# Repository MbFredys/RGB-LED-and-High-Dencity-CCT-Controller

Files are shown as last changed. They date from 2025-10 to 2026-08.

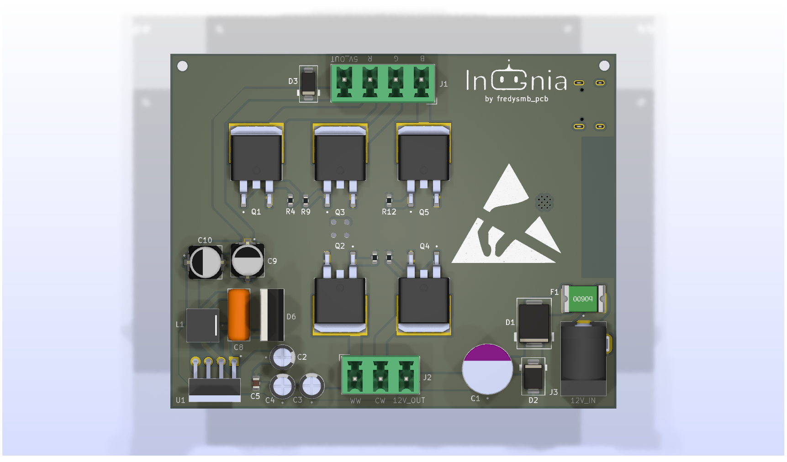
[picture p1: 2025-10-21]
Release/bottom.png

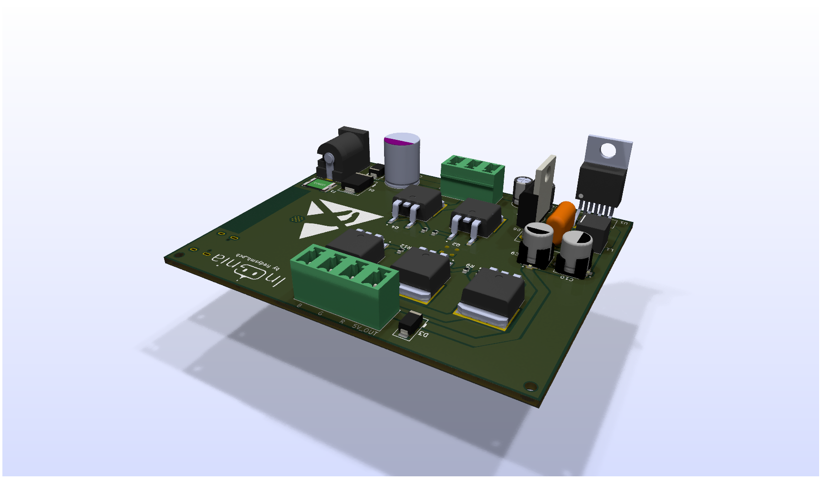
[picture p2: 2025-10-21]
Release/3D-3.png

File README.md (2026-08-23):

# RGB + CCT LED Controller



Five-channel RGB and tunable-white LED-controller PCB based on the ESP32-C3.

> **Project status:** Design and manufacturing documentation completed. The PCB has not been fabricated, thermally characterized, or electrically validated under load.

## Project objective

The project explores a compact controller capable of driving RGB, warm-white, and cool-white LED channels while integrating wireless control, local power conversion, and USB-C programming.

## Hardware architecture

- **Controller:** ESP32-C3-WROOM-02
- **Outputs:** Five low-side PWM channels: R, G, B, warm white, and cool white
- **Switching devices:** IRLZ44N MOSFETs
- **Power input:** 12 V nominal
- **Conversion:** LM2678T-ADJ buck stage and TPS7A20 3.3 V regulation
- **Programming:** USB-C interface
- **Protection:** Input fuse and transient-protection components
- **Connections:** Dedicated RGB and CCT output connectors

## Engineering work

- Defined the functional and power architecture
- Selected the controller, switching devices, regulators, and protection components
- Developed the schematic and PCB layout in KiCad
- Separated high-current and logic routing
- Prepared the BOM and manufacturing documentation

## Key design considerations

- MOSFET conduction losses and gate drive at 3.3 V
- Copper width, connector rating, and total current distribution
- Regulator thermal performance
- PWM return-current paths
- Bulk capacitance near LED outputs
- ESP32 antenna clearance and noise coupling

## Validation still required

Physical testing is required to establish:

- Safe continuous current per channel
- MOSFET and regulator temperatures
- Voltage-drop and connector performance
- PWM behavior with representative LED strips
- Wireless performance during switching
- Protection response and EMC/EMI behavior

The intended current ratings are design targets and must not be treated as validated operating limits.

## License

Licensed under CERN-OHL-W-2.0.

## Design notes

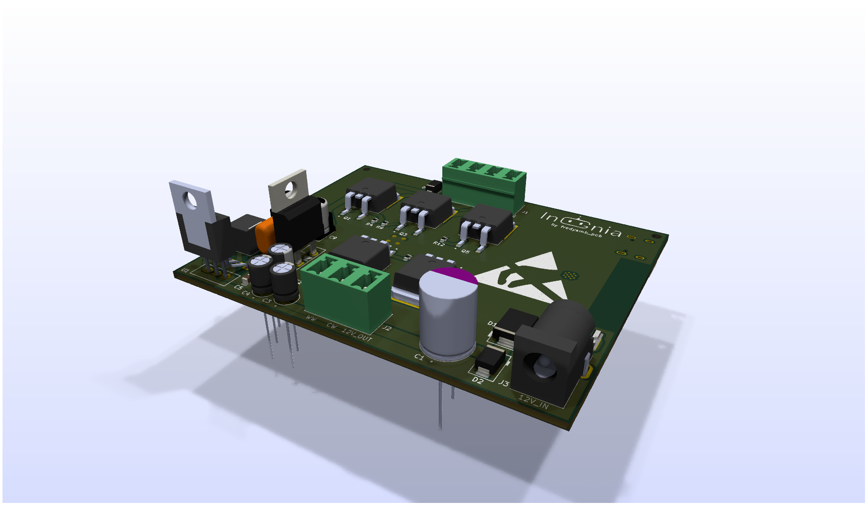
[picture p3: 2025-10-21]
Release/3D-1.png

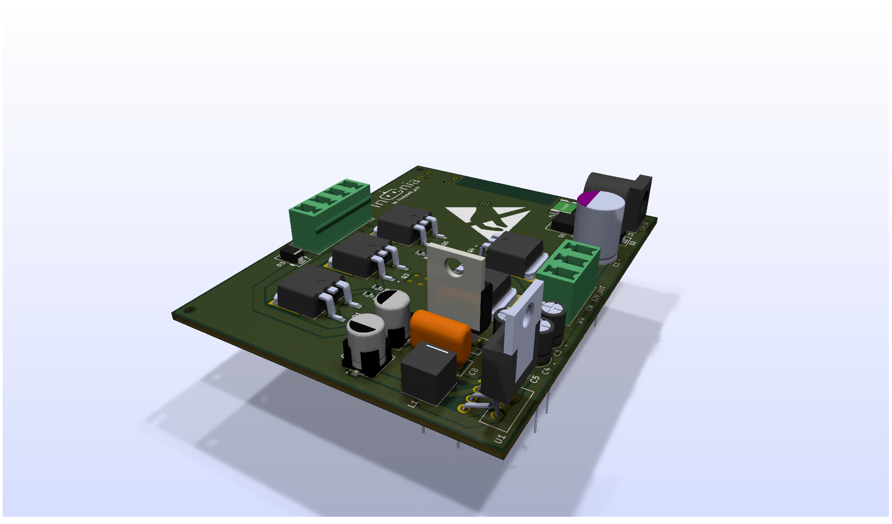
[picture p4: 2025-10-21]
Release/3D-4.png

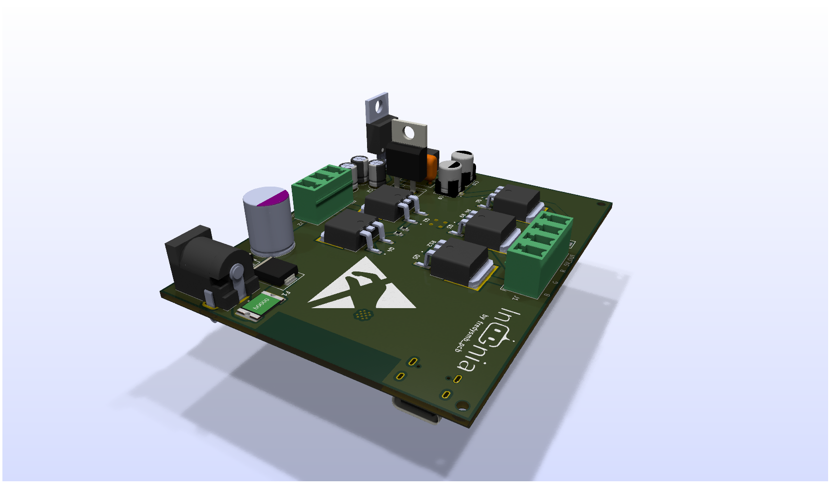
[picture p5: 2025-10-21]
Release/3D-2.png

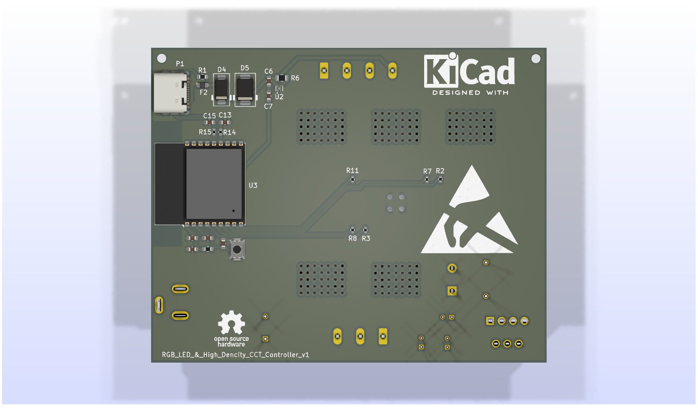
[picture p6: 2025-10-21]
Release/top.png

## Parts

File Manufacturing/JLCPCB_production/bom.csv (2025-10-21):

Designator | Footprint | Quantity | Value | LCSC Part #
C1 | CAPPRD500W60D1000H1300 | 1 | 1000uF
C10, C9 | CAP_EEEFNE181XUV | 2 | 180uF
C11 | 0603 | 1 | 10uF
C12, C14 | 0603 | 2 | 0.1uF
C13, C15 | 0603 | 2 | 22pF
C16, C6, C7 | 0603 | 3 | 1uF
C2, C3, C4 | CAPPRD200W45D500H700 | 3 | 15uF
C5 | 0805 | 1 | 0.47uF
C8 | CAPRR750W60L1030T440H750 | 1 | 0.01uF
D1 | D_SMC | 1 | SS54
D2, D5 | D_SMB | 2 | SMBJ12A
D3 | D_SMA | 1 | SMAJ5.0A
D4 | D_SMA | 1 | SS14
D6 | TO-220-2_Vertical_KA | 1 | MBR735
F1 | FUSC7351X170N | 1 | Polyfuse
F2 | FUSC1608X100N | 1 | Polyfuse
J1 | PhoenixContact_MCV_1,5_4-G-5.08_1x04_P5.08mm_Vertical | 1 | RGB_Strip
J2 | PhoenixContact_MCV_1,5_3-G-5.08_1x03_P5.08mm_Vertical | 1 | CW/WW_Strip
J3 | MPD_EJ503A | 1 | CON_12VDC_IN
L1 | IND_XAL6060-223MEB | 1 | 22uH
P1 | USB_C_Receptacle_GCT_USB4105-xx-A_16P_TopMnt_Horizontal | 1 | USB_C_Plug_USB2.0
Q1, Q2, Q3, Q4, Q5 | TO254P1524X483-4N | 5 | IRLZ44N
R1 | 0603 | 1 | 5.1k
R10, R12, R13, R4, R9 | 0603 | 5 | 10k
R11, R2, R3, R7, R8 | 0402 | 5 | 100
R14, R15 | 0402 | 2 | 22
R5 | 0603 | 1 | 100k
R6 | 0805 | 1 | 100k
SW1 | SW_Push_SPST_NO_Alps_SKRK | 1 | uC_Reset
U1 | TO127P1041X469X2199-7N | 1 | LM2678T-ADJ
U2 | Texas_X2SON-4_1x1mm_P0.65mm | 1 | TPS7A20xxxDQN
U3 | ESP32-C3-WROOM-02 | 1 | ESP32-C3-WROOM-02

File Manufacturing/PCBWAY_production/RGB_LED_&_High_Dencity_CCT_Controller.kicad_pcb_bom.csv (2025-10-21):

Designator | Quantity | Value | Footprint | Package | MPN | DNP | Mount_Type
C1 | 1 | 1000uF | CAPPRD500W60D1000H1300 |  |  |  | tht
C10, C9 | 2 | 180uF | CAP_EEEFNE181XUV |  |  |  | smt
C11 | 1 | 10uF | C_0603_1608Metric |  |  |  | smt
C12, C14 | 2 | 0.1uF | C_0603_1608Metric |  |  |  | smt
C13, C15 | 2 | 22pF | C_0603_1608Metric |  |  |  | smt
C16, C6, C7 | 3 | 1uF | C_0603_1608Metric |  |  |  | smt
C2, C3, C4 | 3 | 15uF | CAPPRD200W45D500H700 |  |  |  | tht
C5 | 1 | 0.47uF | C_0805_2012Metric |  |  |  | smt
C8 | 1 | 0.01uF | CAPRR750W60L1030T440H750 |  |  |  | tht
D1 | 1 | SS54 | D_SMC |  |  |  | smt
D2, D5 | 2 | SMBJ12A | D_SMB |  |  |  | smt
D3 | 1 | SMAJ5.0A | D_SMA |  |  |  | smt
D4 | 1 | SS14 | D_SMA |  |  |  | smt
D6 | 1 | MBR735 | TO-220-2_Vertical_KA |  |  |  | tht
F1 | 1 | Polyfuse | FUSC7351X170N |  |  |  | smt
F2 | 1 | Polyfuse | FUSC1608X100N |  |  |  | smt
J1 | 1 | RGB_Strip | PhoenixContact_MCV_1,5_4-G-5.08_1x04_P5.08mm_Vertical |  |  |  | tht
J2 | 1 | CW/WW_Strip | PhoenixContact_MCV_1,5_3-G-5.08_1x03_P5.08mm_Vertical |  |  |  | tht
J3 | 1 | CON_12VDC_IN | MPD_EJ503A |  |  |  | tht
L1 | 1 | 22uH | IND_XAL6060-223MEB |  |  |  | smt
P1 | 1 | USB_C_Plug_USB2.0 | USB_C_Receptacle_GCT_USB4105-xx-A_16P_TopMnt_Horizontal |  |  |  | smt
Q1, Q2, Q3, Q4, Q5 | 5 | IRLZ44N | TO254P1524X483-4N |  |  |  | smt
R1 | 1 | 5.1k | R_0603_1608Metric |  |  |  | smt
R10, R12, R13, R4, R9 | 5 | 10k | R_0603_1608Metric |  |  |  | smt
R11, R2, R3, R7, R8 | 5 | 100 | R_0402_1005Metric |  |  |  | smt
R14, R15 | 2 | 22 | R_0402_1005Metric |  |  |  | smt
R5 | 1 | 100k | R_0603_1608Metric |  |  |  | smt
R6 | 1 | 100k | R_0805_2012Metric |  |  |  | smt
SW1 | 1 | uC_Reset | SW_Push_SPST_NO_Alps_SKRK |  |  |  | smt
U1 | 1 | LM2678T-ADJ | TO127P1041X469X2199-7N |  |  |  | tht
U2 | 1 | TPS7A20xxxDQN | Texas_X2SON-4_1x1mm_P0.65mm |  |  |  | smt
U3 | 1 | ESP32-C3-WROOM-02 | ESP32-C3-WROOM-02 |  |  |  | smt

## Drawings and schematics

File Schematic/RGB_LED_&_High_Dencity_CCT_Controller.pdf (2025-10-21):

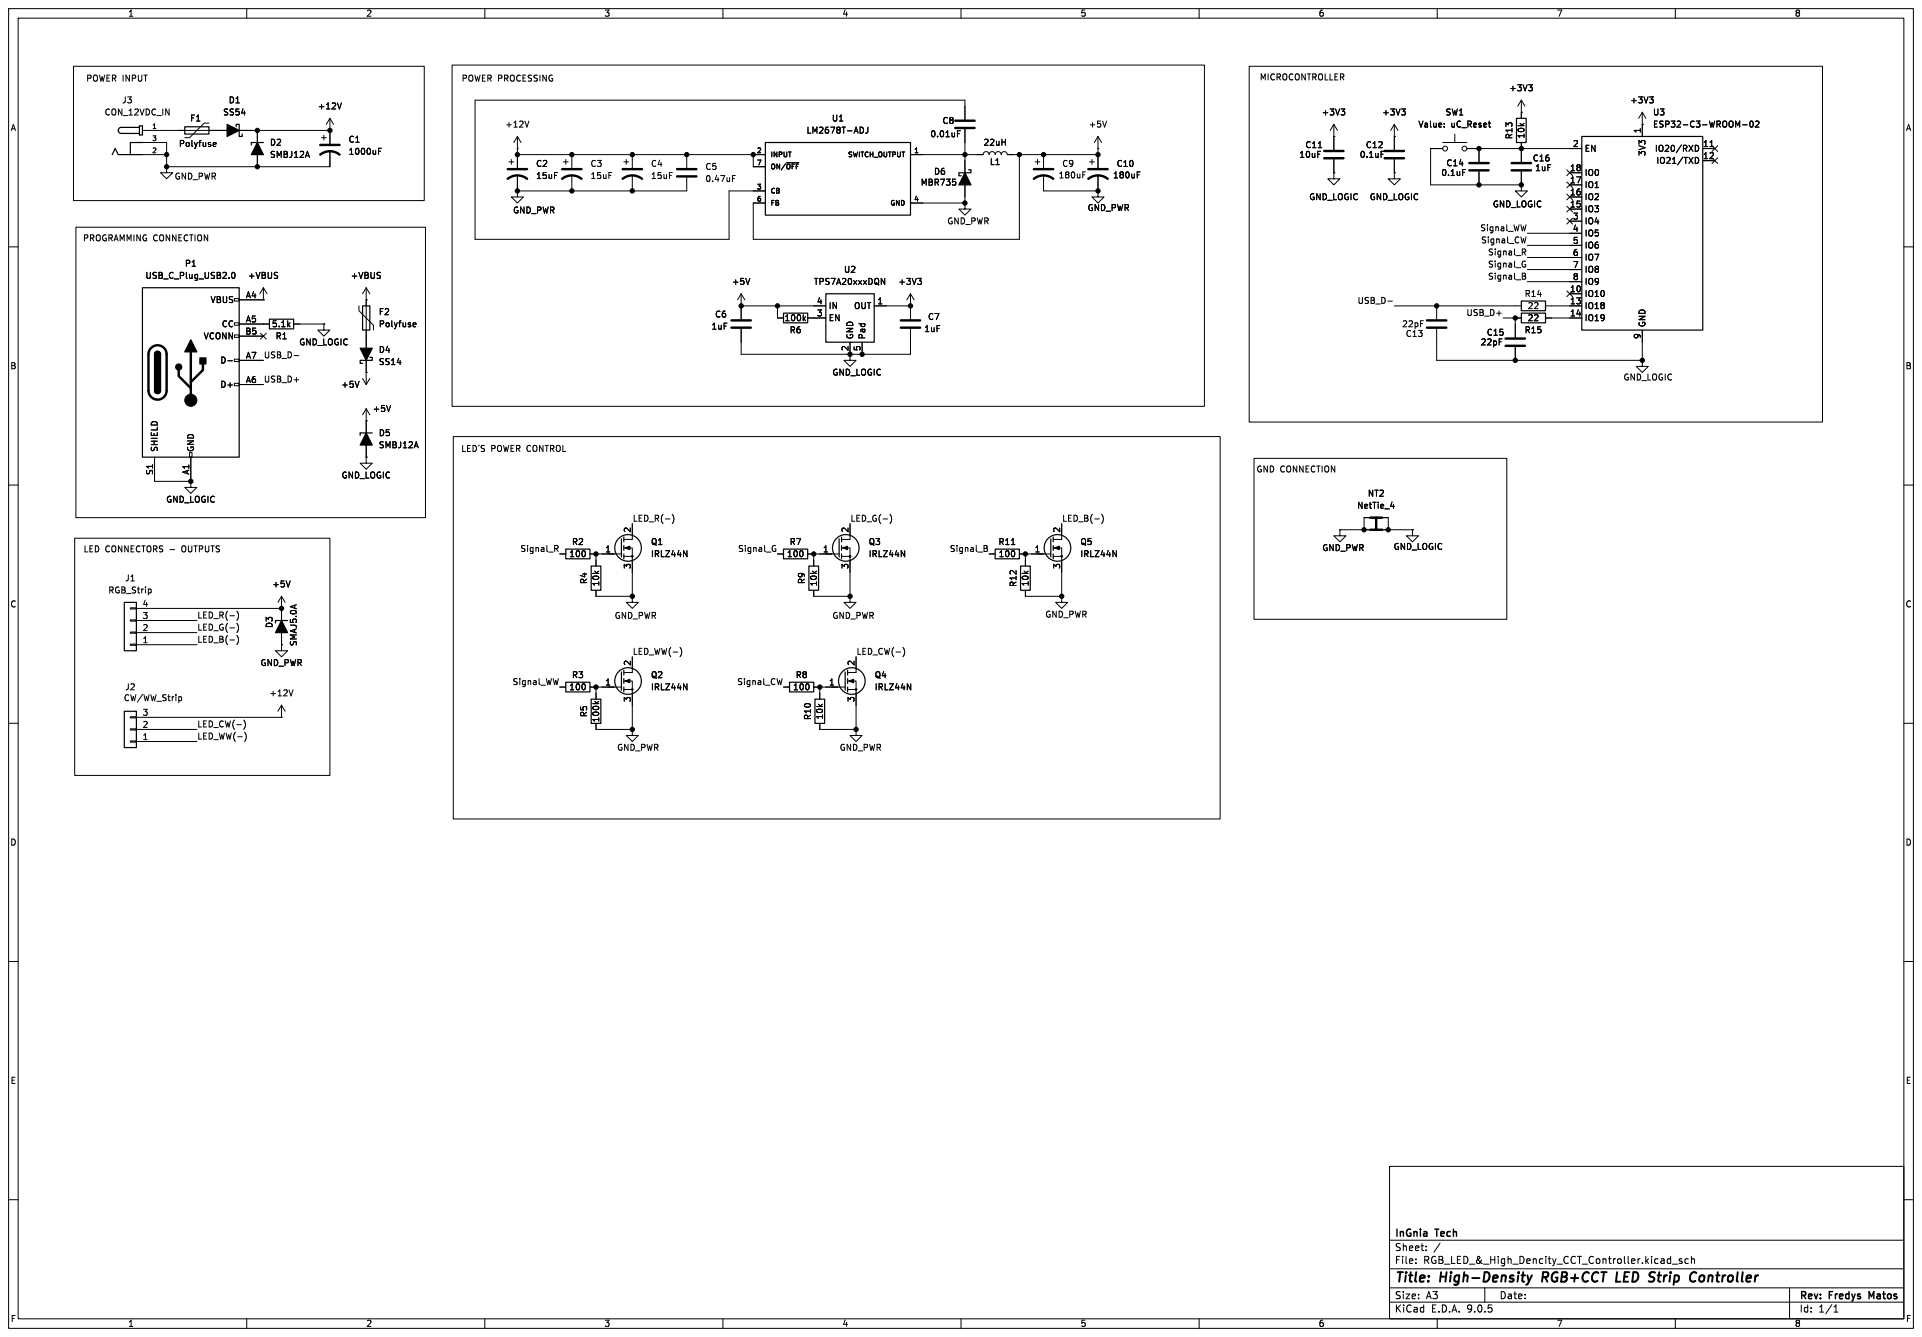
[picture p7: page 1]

POWER INPUT PROGRAMMING CONNECTION

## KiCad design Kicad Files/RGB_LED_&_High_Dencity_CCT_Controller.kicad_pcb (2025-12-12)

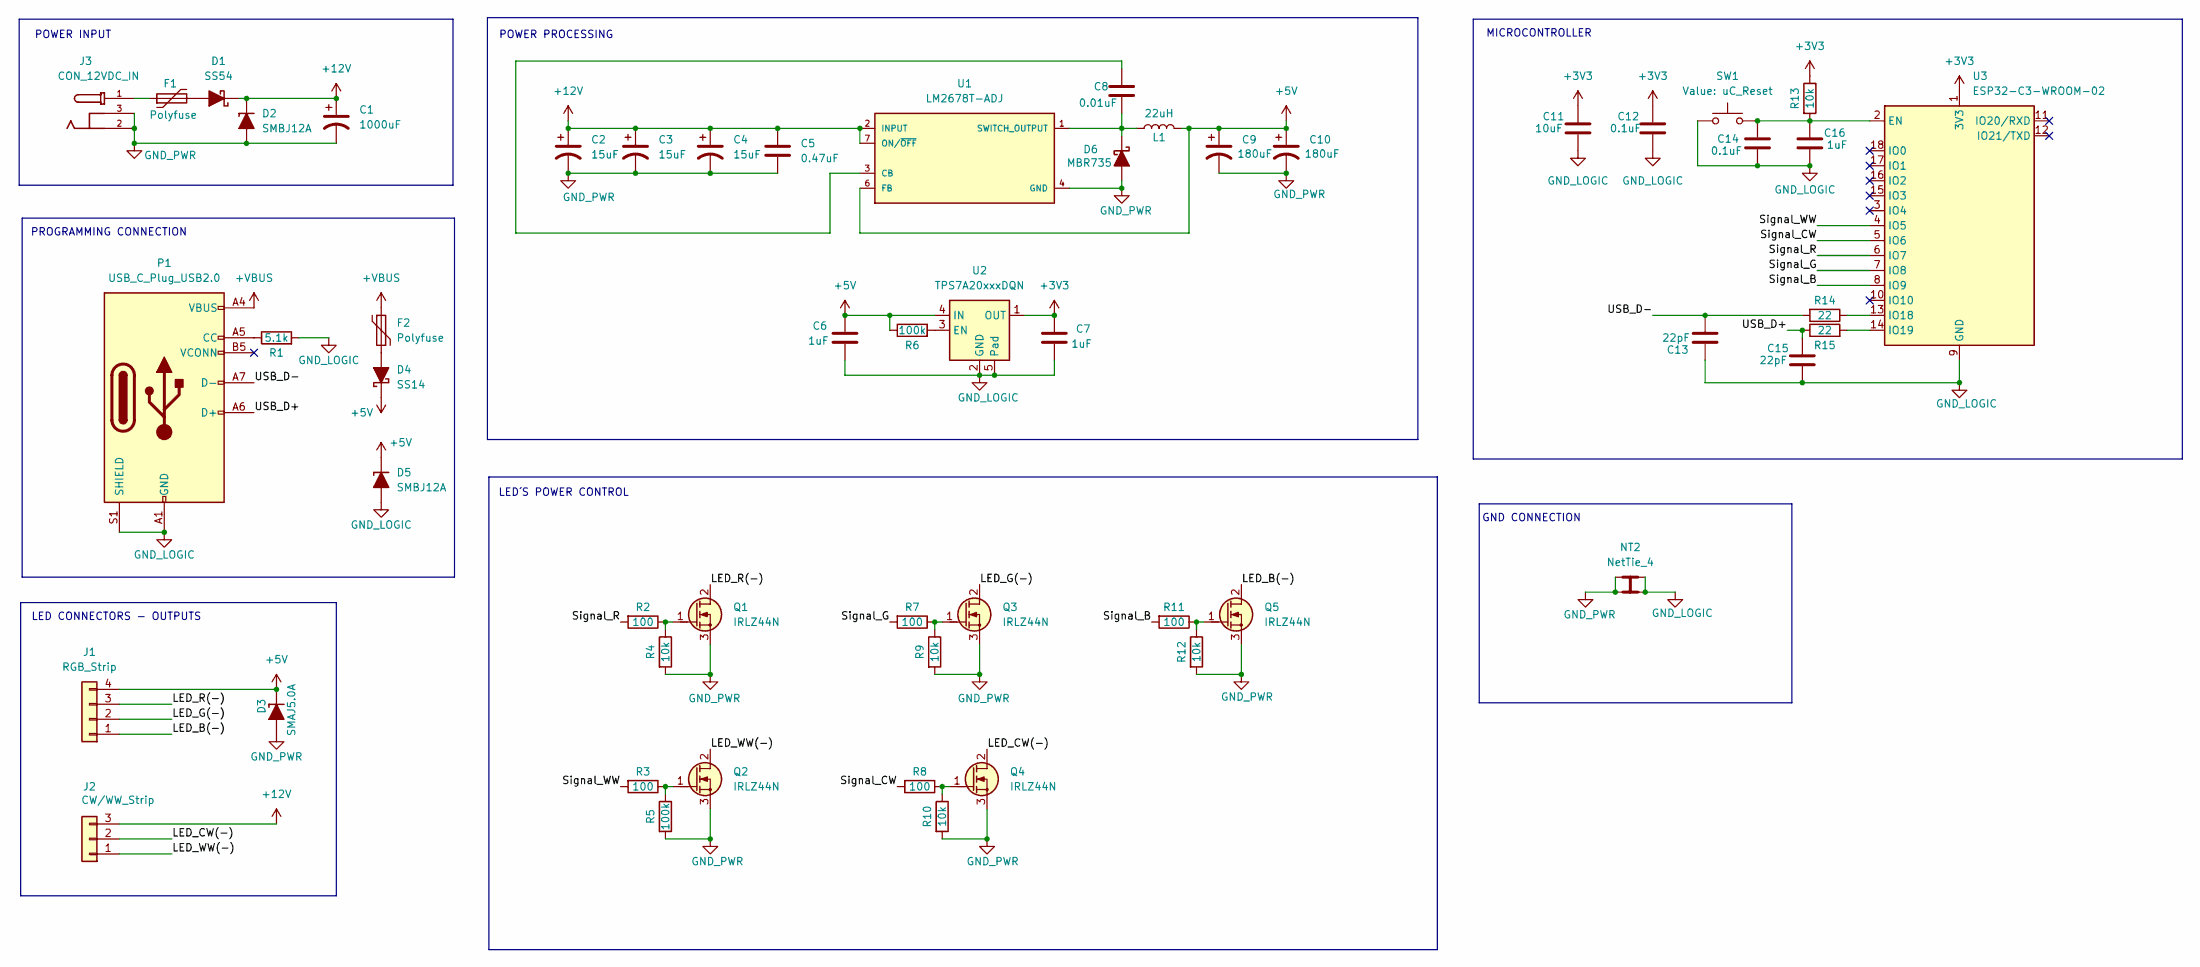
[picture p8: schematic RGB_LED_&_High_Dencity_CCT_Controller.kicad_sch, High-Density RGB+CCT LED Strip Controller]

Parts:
C1: 1000uF; CAPPRD500W60D1000H1300; MPN 16SEPF1000M; LCSC PN C128486
C2, C3, C4: 15uF; CAPPRD200W45D500H700; MPN EEA-GA1E150; LCSC PN C1580740
C5: 0.47uF; C_0805_2012Metric; MPN GRM155R71C474KE01D; LCSC PN C471404
C6, C7: 1uF; C_0603_1608Metric; MPN CL10A105KB8NNNC; LCSC PN C15849
C8: 0.01uF; CAPRR750W60L1030T440H750; MPN ECQE4123JF; LCSC PN C48579278
C9, C10: 180uF; CAP_EEEFNE181XUV; MPN EEEFNE181XUV; LCSC PN C540948
C11: 10uF; C_0603_1608Metric; MPN GRM155R71C474KE01D; LCSC PN 0402
C12, C14: 0.1uF; C_0603_1608Metric; MPN GRM155R71C474KE01D; LCSC PN 0402
C13, C15: 22pF; C_0603_1608Metric; MPN GRM155R71C474KE01D; LCSC PN 0402
C16: 1uF; C_0603_1608Metric; MPN GRM155R71C474KE01D; LCSC PN 0402
D1: SS54; D_SMC; MPN SS54; LCSC PN C22452
D2: SMBJ12A; D_SMB; MPN SMBJ12A; LCSC PN C151251
D3: SMAJ5.0A; D_SMA; MPN SMAJ5.0A; LCSC PN C83329
D4: SS14; D_SMA
D5: SMBJ12A; D_SMB
D6: MBR735; TO-220-2_Vertical_KA; MPN MBR735; LCSC PN C3759044
F1: Polyfuse; FUSC7351X170N; MPN 0ZCF0600FF2C; LCSC PN C20040854
F2: Polyfuse; FUSC1608X100N
J1: RGB_Strip; PhoenixContact_MCV_1,5_4-G-5.08_1x04_P5.08mm_Vertical
J2: CW/WW_Strip; PhoenixContact_MCV_1,5_3-G-5.08_1x03_P5.08mm_Vertical
J3: CON_12VDC_IN; MPD_EJ503A; MPN EJ503A; LCSC PN C3095117
L1: 22uH; IND_XAL6060-223MEB; MPN FXL1040-220-M; LCSC PN C475917
NT2: NetTie_4; NetTie-4_THT_Pad1.0mm
P1: USB_C_Plug_USB2.0; USB_C_Receptacle_GCT_USB4105-xx-A_16P_TopMnt_Horizontal
Q1, Q2, Q3, Q4, Q5: IRLZ44N; TO254P1524X483-4N; MPN IRLZ44NSPBF-VB; LCSC PN C19188232
R1: 5.1k; R_0603_1608Metric
R2, R3, R7, R8, R11: 100; R_0402_1005Metric
R4, R9, R10, R12, R13: 10k; R_0603_1608Metric
R5: 100k; R_0603_1608Metric
R6: 100k; R_0805_2012Metric; MPN RC0805FR-07100KL; LCSC PN C96346
R14, R15: 22; R_0402_1005Metric
SW1: uC_Reset; SW_Push_SPST_NO_Alps_SKRK
U1: LM2678T-ADJ; TO127P1041X469X2199-7N
U2: TPS7A20xxxDQN; Texas_X2SON-4_1x1mm_P0.65mm
U3: ESP32-C3-WROOM-02; MPN ESP32-C3-WROOM-02-N4; LCSC PN C2934560

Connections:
+3V3: C7.1, C11.1, C12.1, R13.1, U2.1 (OUT), U3.1 (3V3)
+5V: C6.1, C9.1, C10.1, D3.1 (K), D4.1 (K), D5.1 (K), J1.4, L1.2, R6.1, U1.6 (FB), U2.4 (IN)
+12V: C1.1, C2.1, C3.1, C4.1, C5.1, D1.1 (K), D2.1 (K), J2.3, U1.2 (INPUT), U1.7 (ON/~OFF)
+VBUS: F2.1, P1.A4 (VBUS), P1.A9 (VBUS), P1.B4 (VBUS), P1.B9 (VBUS)
/LED_B(-): J1.1, Q5.2 (D)
/LED_CW(-): J2.2, Q4.2 (D)
/LED_G(-): J1.2, Q3.2 (D)
/LED_R(-): J1.3, Q1.2 (D)
/LED_WW(-): J2.1, Q2.2 (D)
/Signal_B: R11.2, U3.8 (IO9)
/Signal_CW: R8.2, U3.5 (IO6)
/Signal_G: R7.2, U3.7 (IO8)
/Signal_R: R2.2, U3.6 (IO7)
/Signal_WW: R3.2, U3.4 (IO5)
/USB_D+: C15.1, P1.A6 (D+), R15.1
/USB_D-: C13.1, P1.A7 (D-), R14.2
GND_LOGIC: C6.2, C7.2, C11.2, C12.2, C13.2, C14.1, C15.2, C16.2, D5.2 (A), NT2.2, NT2.4, P1.A1 (GND), P1.A12 (GND), P1.B1 (GND), P1.B12 (GND), P1.S1 (SHIELD), R1.2, SW1.1, U2.2 (GND), U2.5 (Pad), U3.9 (GND), U3.19 (GND)
GND_PWR: C1.2, C2.2, C3.2, C4.2, C5.2, C9.2, C10.2, D2.2 (A), D3.2 (A), D6.2 (A), J3.2, J3.3, NT2.1, NT2.3, Q1.3 (S), Q2.3 (S), Q3.3 (S), Q4.3 (S), Q5.3 (S), R4.2, R5.2, R9.2, R10.2, R12.2, U1.4 (GND)
unnamed: D1.2 (A), F1.2
unnamed: D4.2 (A), F2.2
unnamed: C8.2, D6.1 (K), L1.1, U1.1 (SWITCH_OUTPUT)
unnamed: F1.1, J3.1
unnamed: P1.A5 (CC), R1.1
unnamed: Q1.1 (G), R2.1, R4.1
unnamed: Q2.1 (G), R3.1, R5.1
unnamed: Q3.1 (G), R7.1, R9.1
unnamed: Q4.1 (G), R8.1, R10.1
unnamed: Q5.1 (G), R11.1, R12.1
unnamed: C8.1, U1.3 (CB)
unnamed: R6.2, U2.3 (EN)
unnamed: C14.2, C16.1, R13.2, SW1.2, U3.2 (EN)
unnamed: R14.1, U3.13 (IO18)
unnamed: R15.2, U3.14 (IO19)

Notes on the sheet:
POWER PROCESSING
POWER INPUT
GND CONNECTION
LED CONNECTORS - OUTPUTS
LED´S POWER CONTROL
MICROCONTROLLER
PROGRAMMING CONNECTION

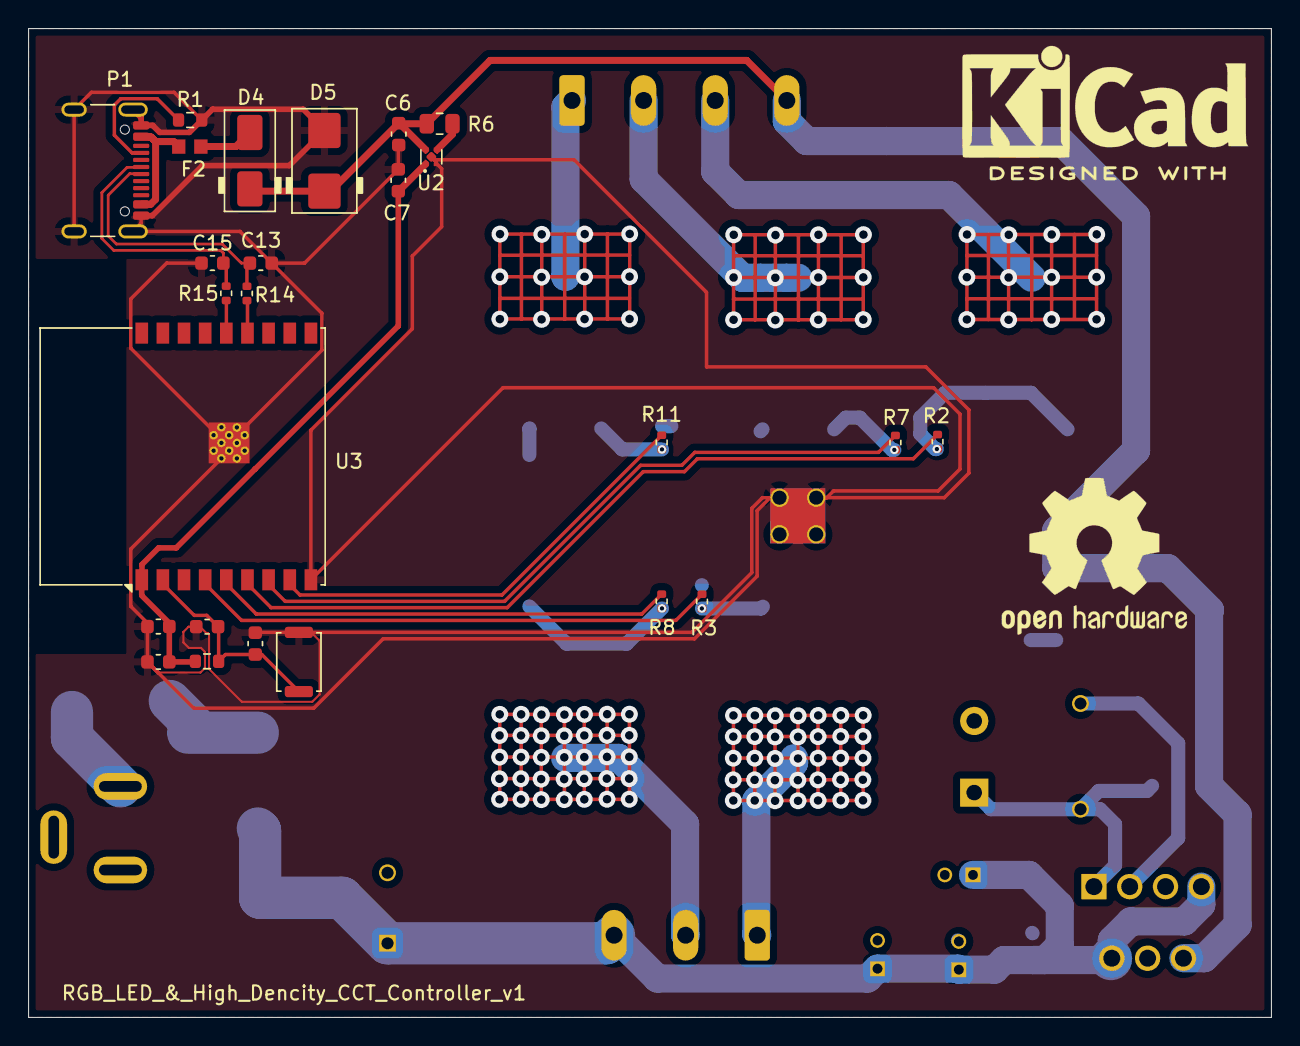
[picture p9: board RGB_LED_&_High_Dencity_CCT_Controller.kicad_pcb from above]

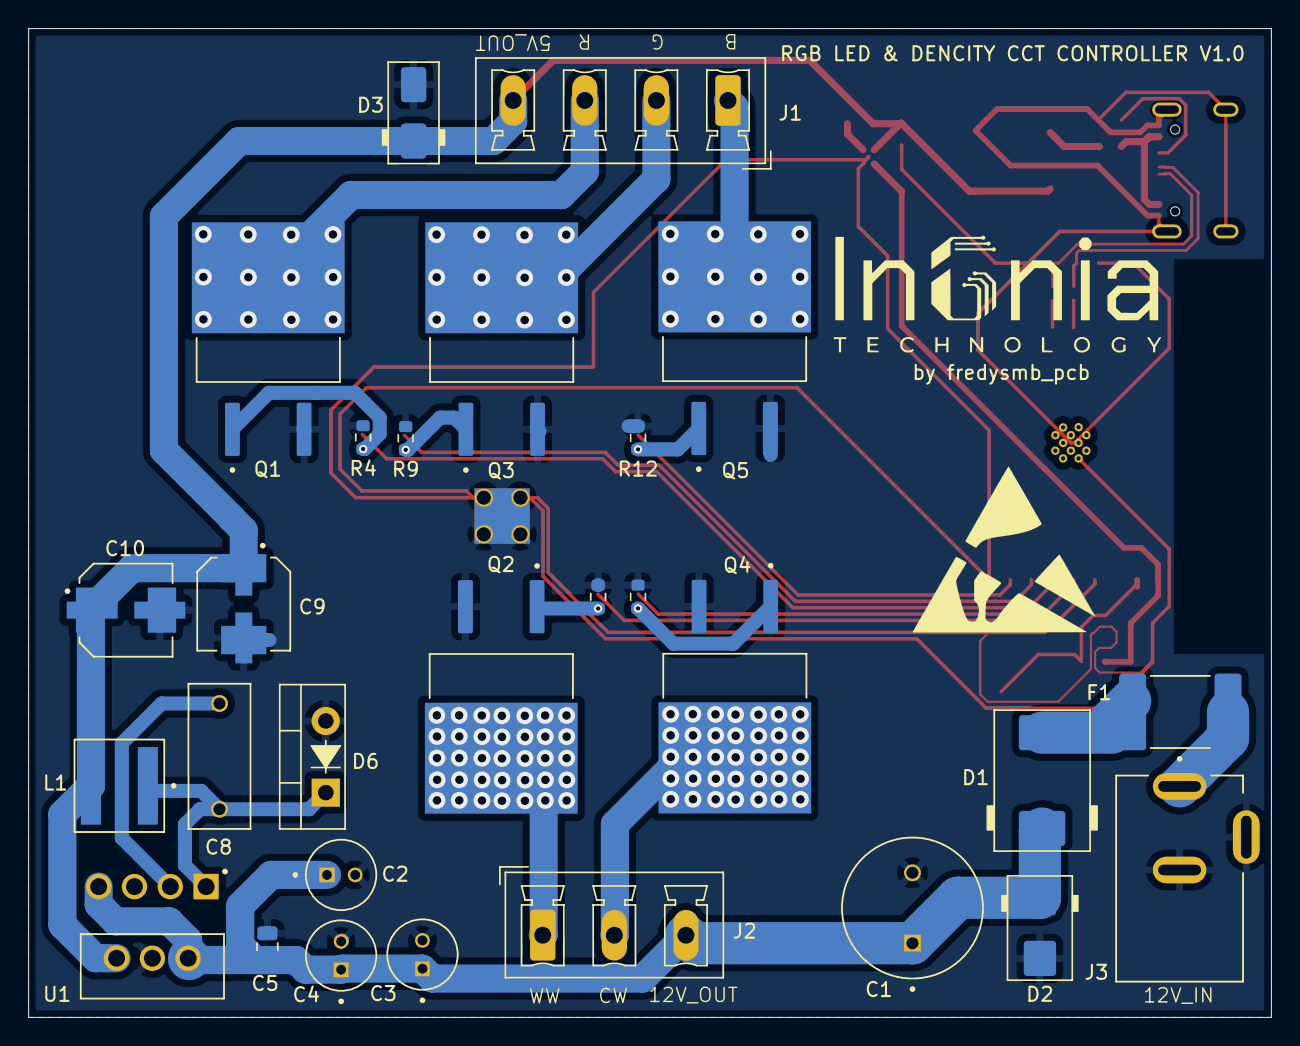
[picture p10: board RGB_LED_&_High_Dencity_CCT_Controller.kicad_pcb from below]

Board: 2 copper layers, 88.2 x 70.2 mm, 54 parts (28 on the bottom side), 33 nets.

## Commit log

2025-10-20 Revise README for PCB-RGB+CCT-LED-Controller
    Updated README to reflect new PCB design and features.
2025-12-12 Add initial Kicad 9.0 documentation

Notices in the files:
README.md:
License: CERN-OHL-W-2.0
